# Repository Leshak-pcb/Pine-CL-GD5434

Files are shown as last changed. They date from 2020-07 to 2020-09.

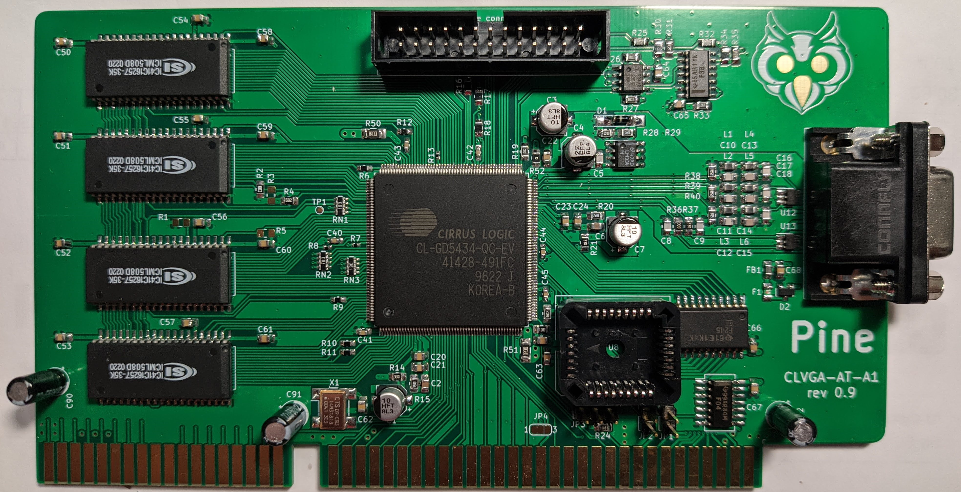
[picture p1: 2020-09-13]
Photo.jpg

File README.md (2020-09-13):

# Pine-CL-GD5434
CL-GD5434-based ISA VGA card.
Tested, works, but may still contain minor errors. Feature connector and 64k rom option are not tested yet.
Notes:
1) R1-R5 are configuration resistors, install R2 & R4 for fast DRAM, R2 & R3 for slow DRAM. Check CL-GD543x databook if you need more info.
2) U10 - optional, provides DD2B support (works with generic PCI BIOS).
3) FB1-F1-D2-C68 - DDC monitor power, remove if not using U10. D2 - BAT54 or equivalent, F1 - 200mA poly fuse.
4) U11 - optional, 93C46 used to store video modes supported by your monitor.
5) U12, U13 - optional, ESD & hot-plug protection.
6) C90-C92 - 10uF - 47uF 6.3V+
7) D1 can be replaced with 1n4148

Creative Commons Attribution-ShareAlike 4.0 International License. See https://creativecommons.org/licenses/by-sa/4.0/.

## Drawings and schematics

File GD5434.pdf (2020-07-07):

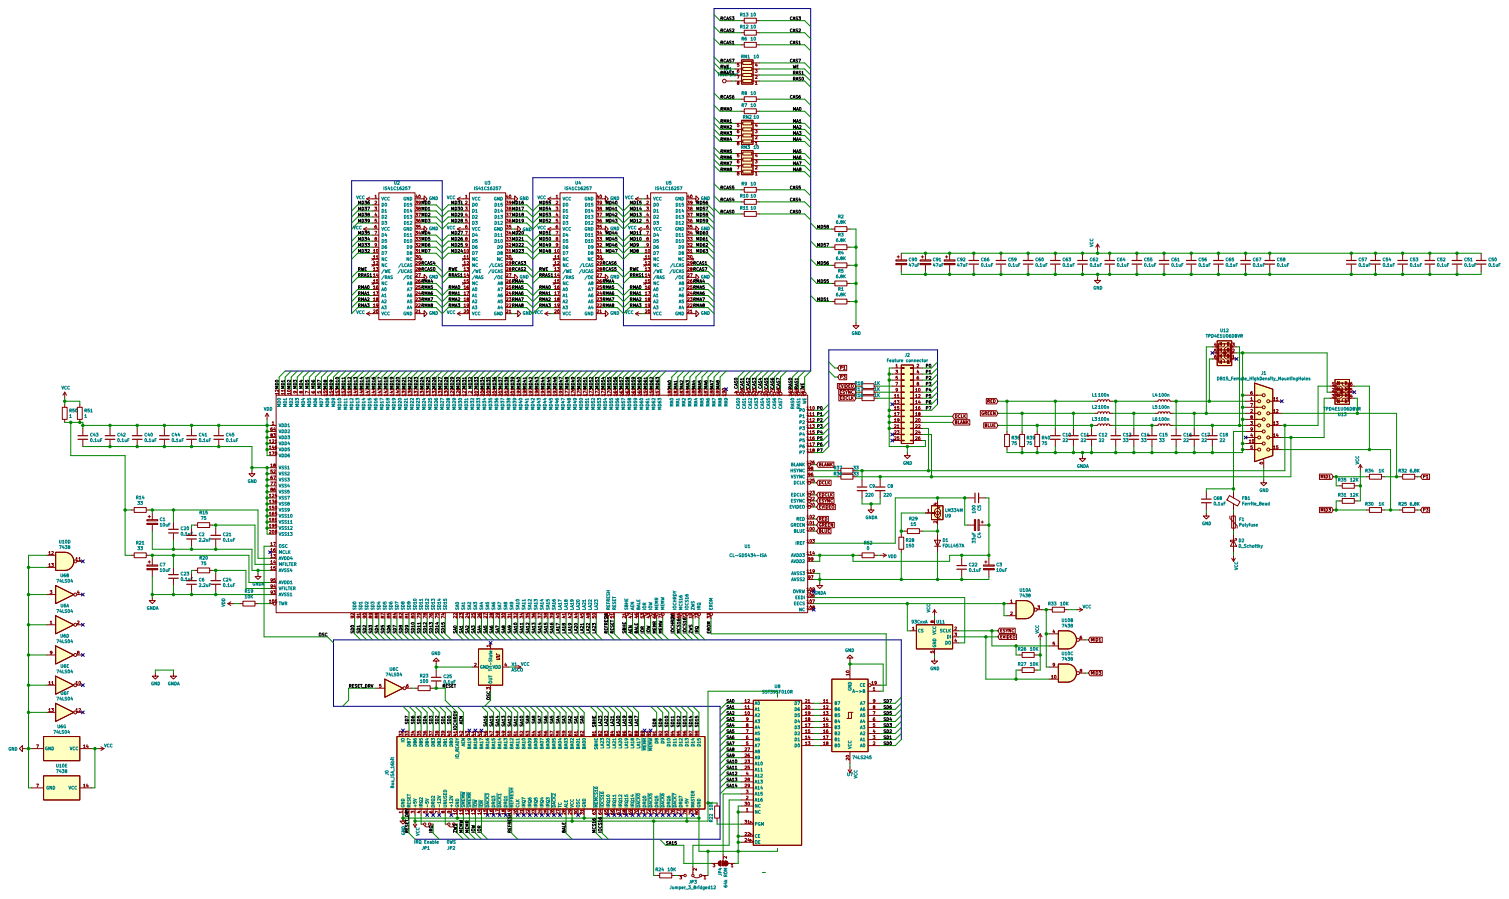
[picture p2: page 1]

4 LA17 40 LA18 41 LA19 42 IOW 43 LA20 44 LA21 45 BALE 46 AEN 47 LA22 48 IOCHRDY 49 MD7

1 GND 10 SMEMW 11 SMEMR 12 IOW 13 IOR 14 DACK3 15 DRQ3 16 DACK1 17 DRQ1 18 REFRESH 19 RESET

2 CLK 20 IRQ7 21 IRQ6 22 IRQ5 23 IRQ4 24 IRQ3 25 DACK2 26 TC 27 ALE 28 VCC 29 +5V

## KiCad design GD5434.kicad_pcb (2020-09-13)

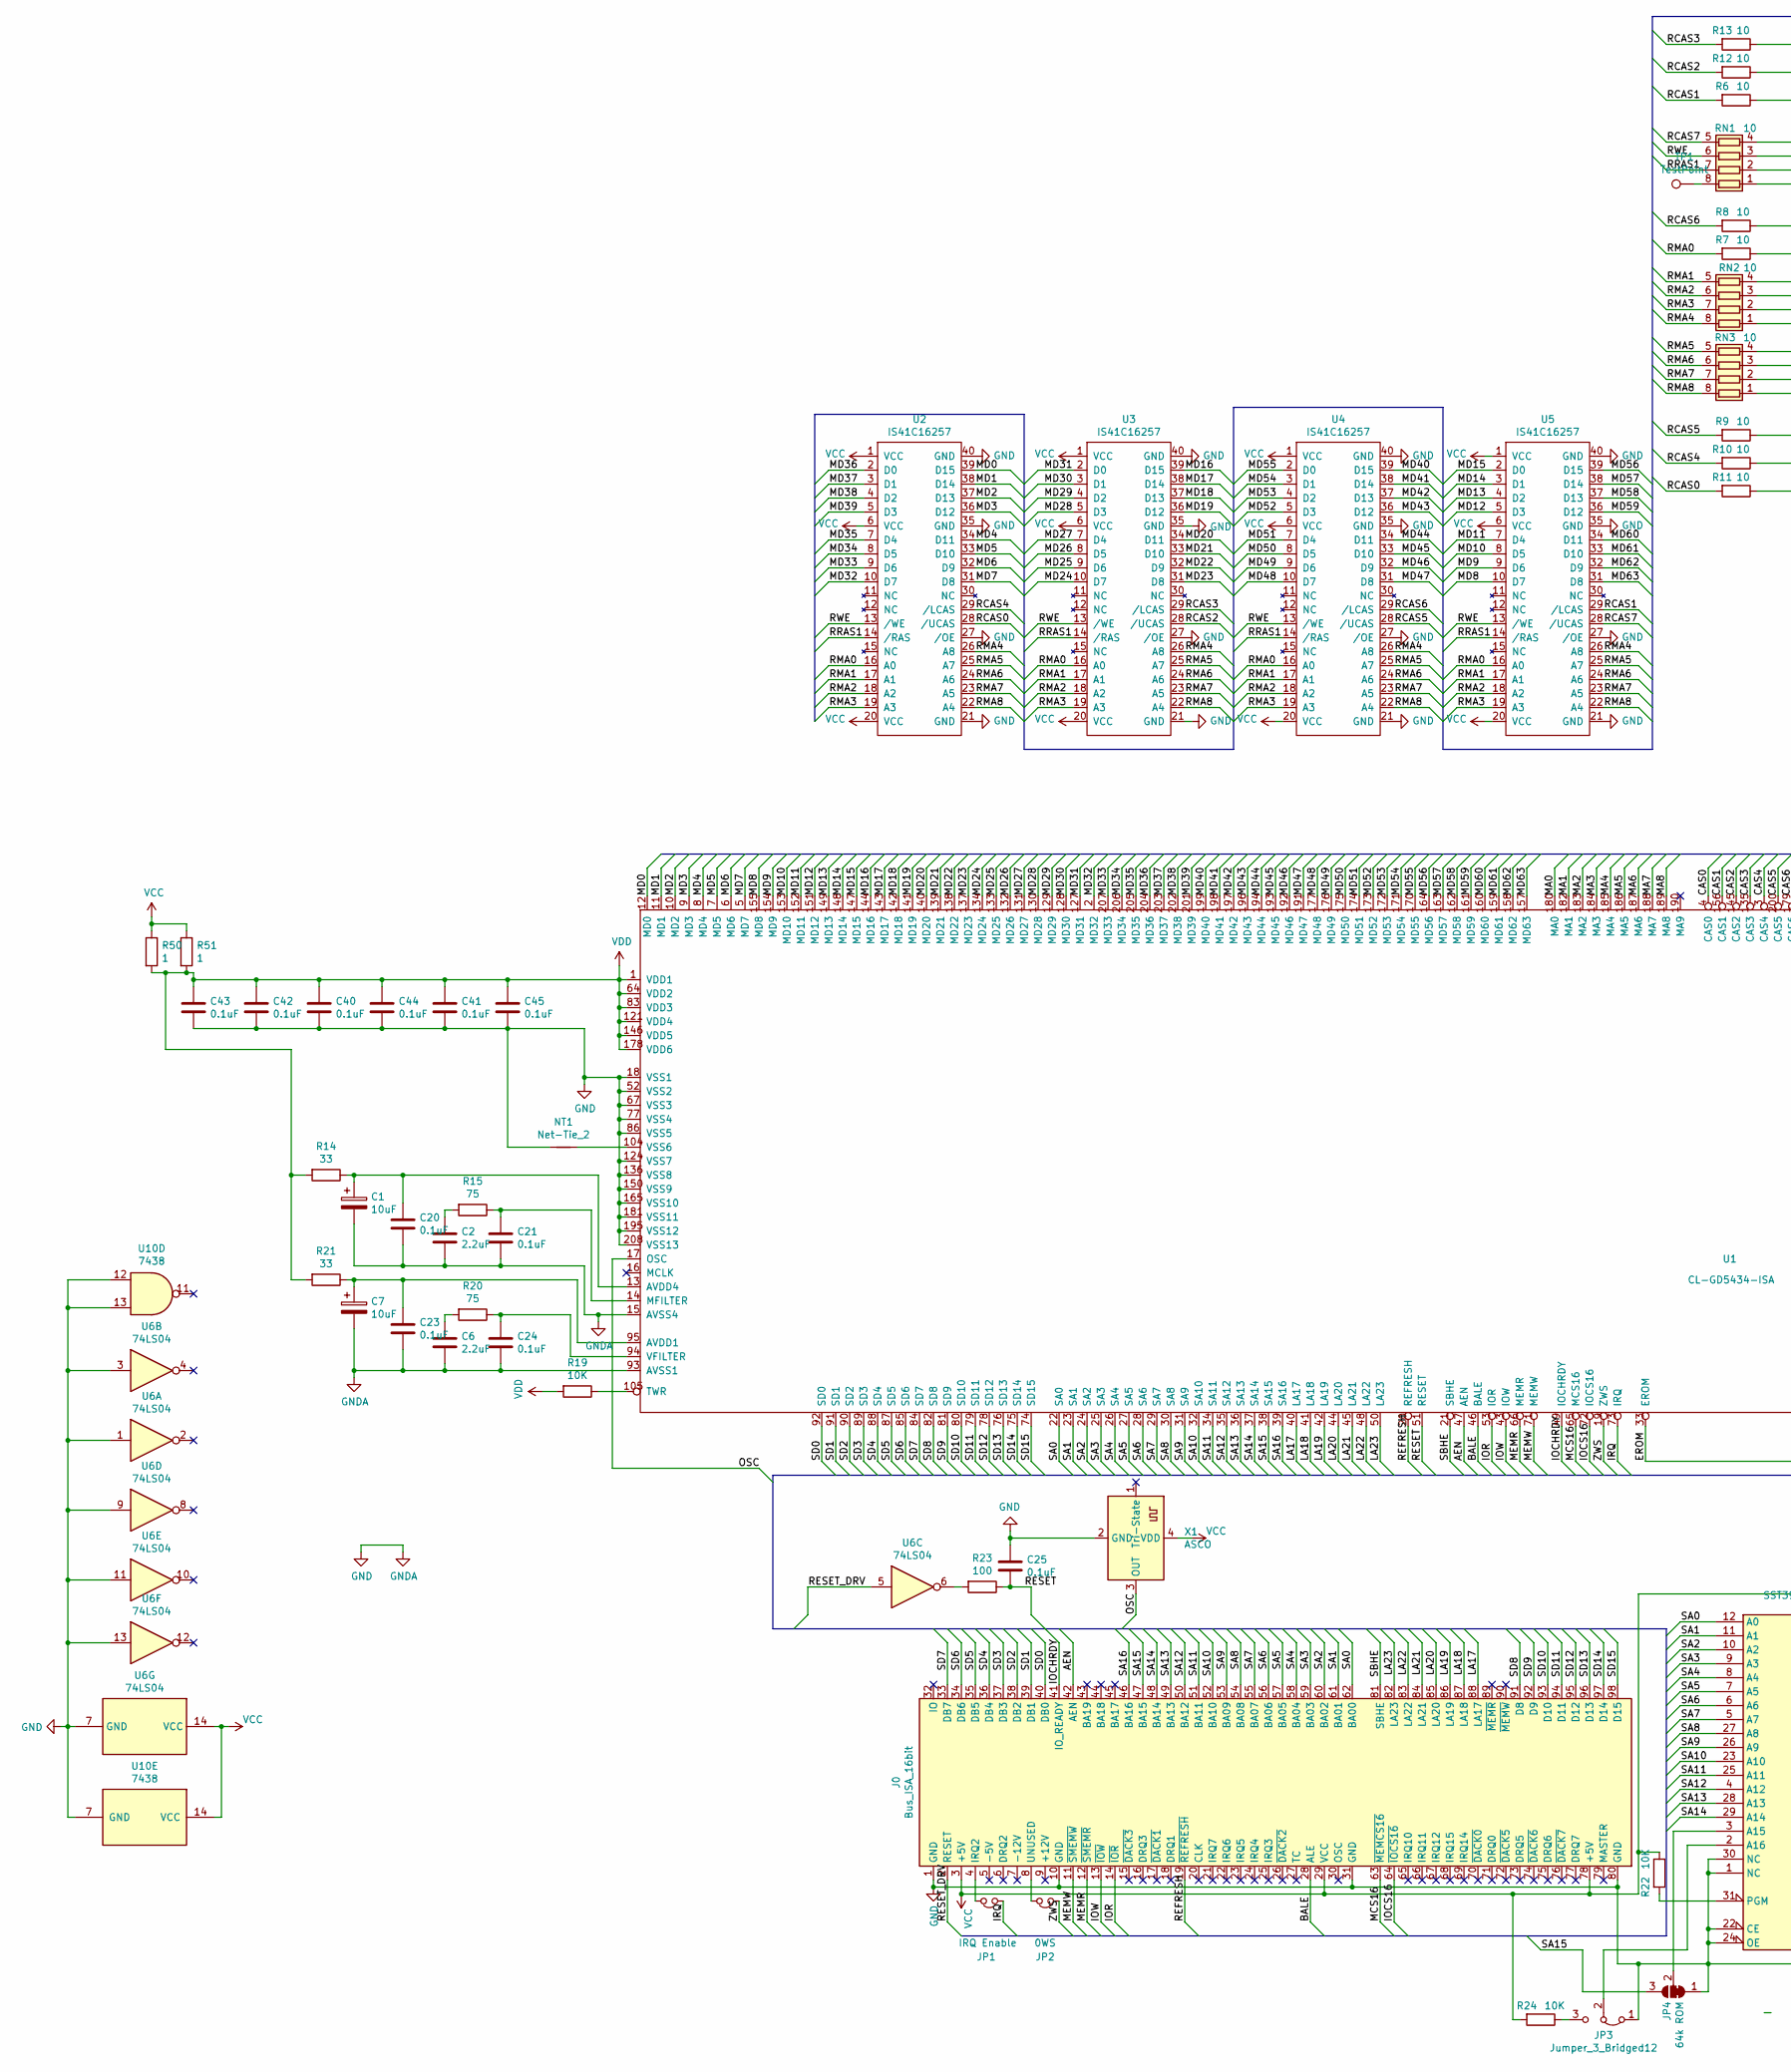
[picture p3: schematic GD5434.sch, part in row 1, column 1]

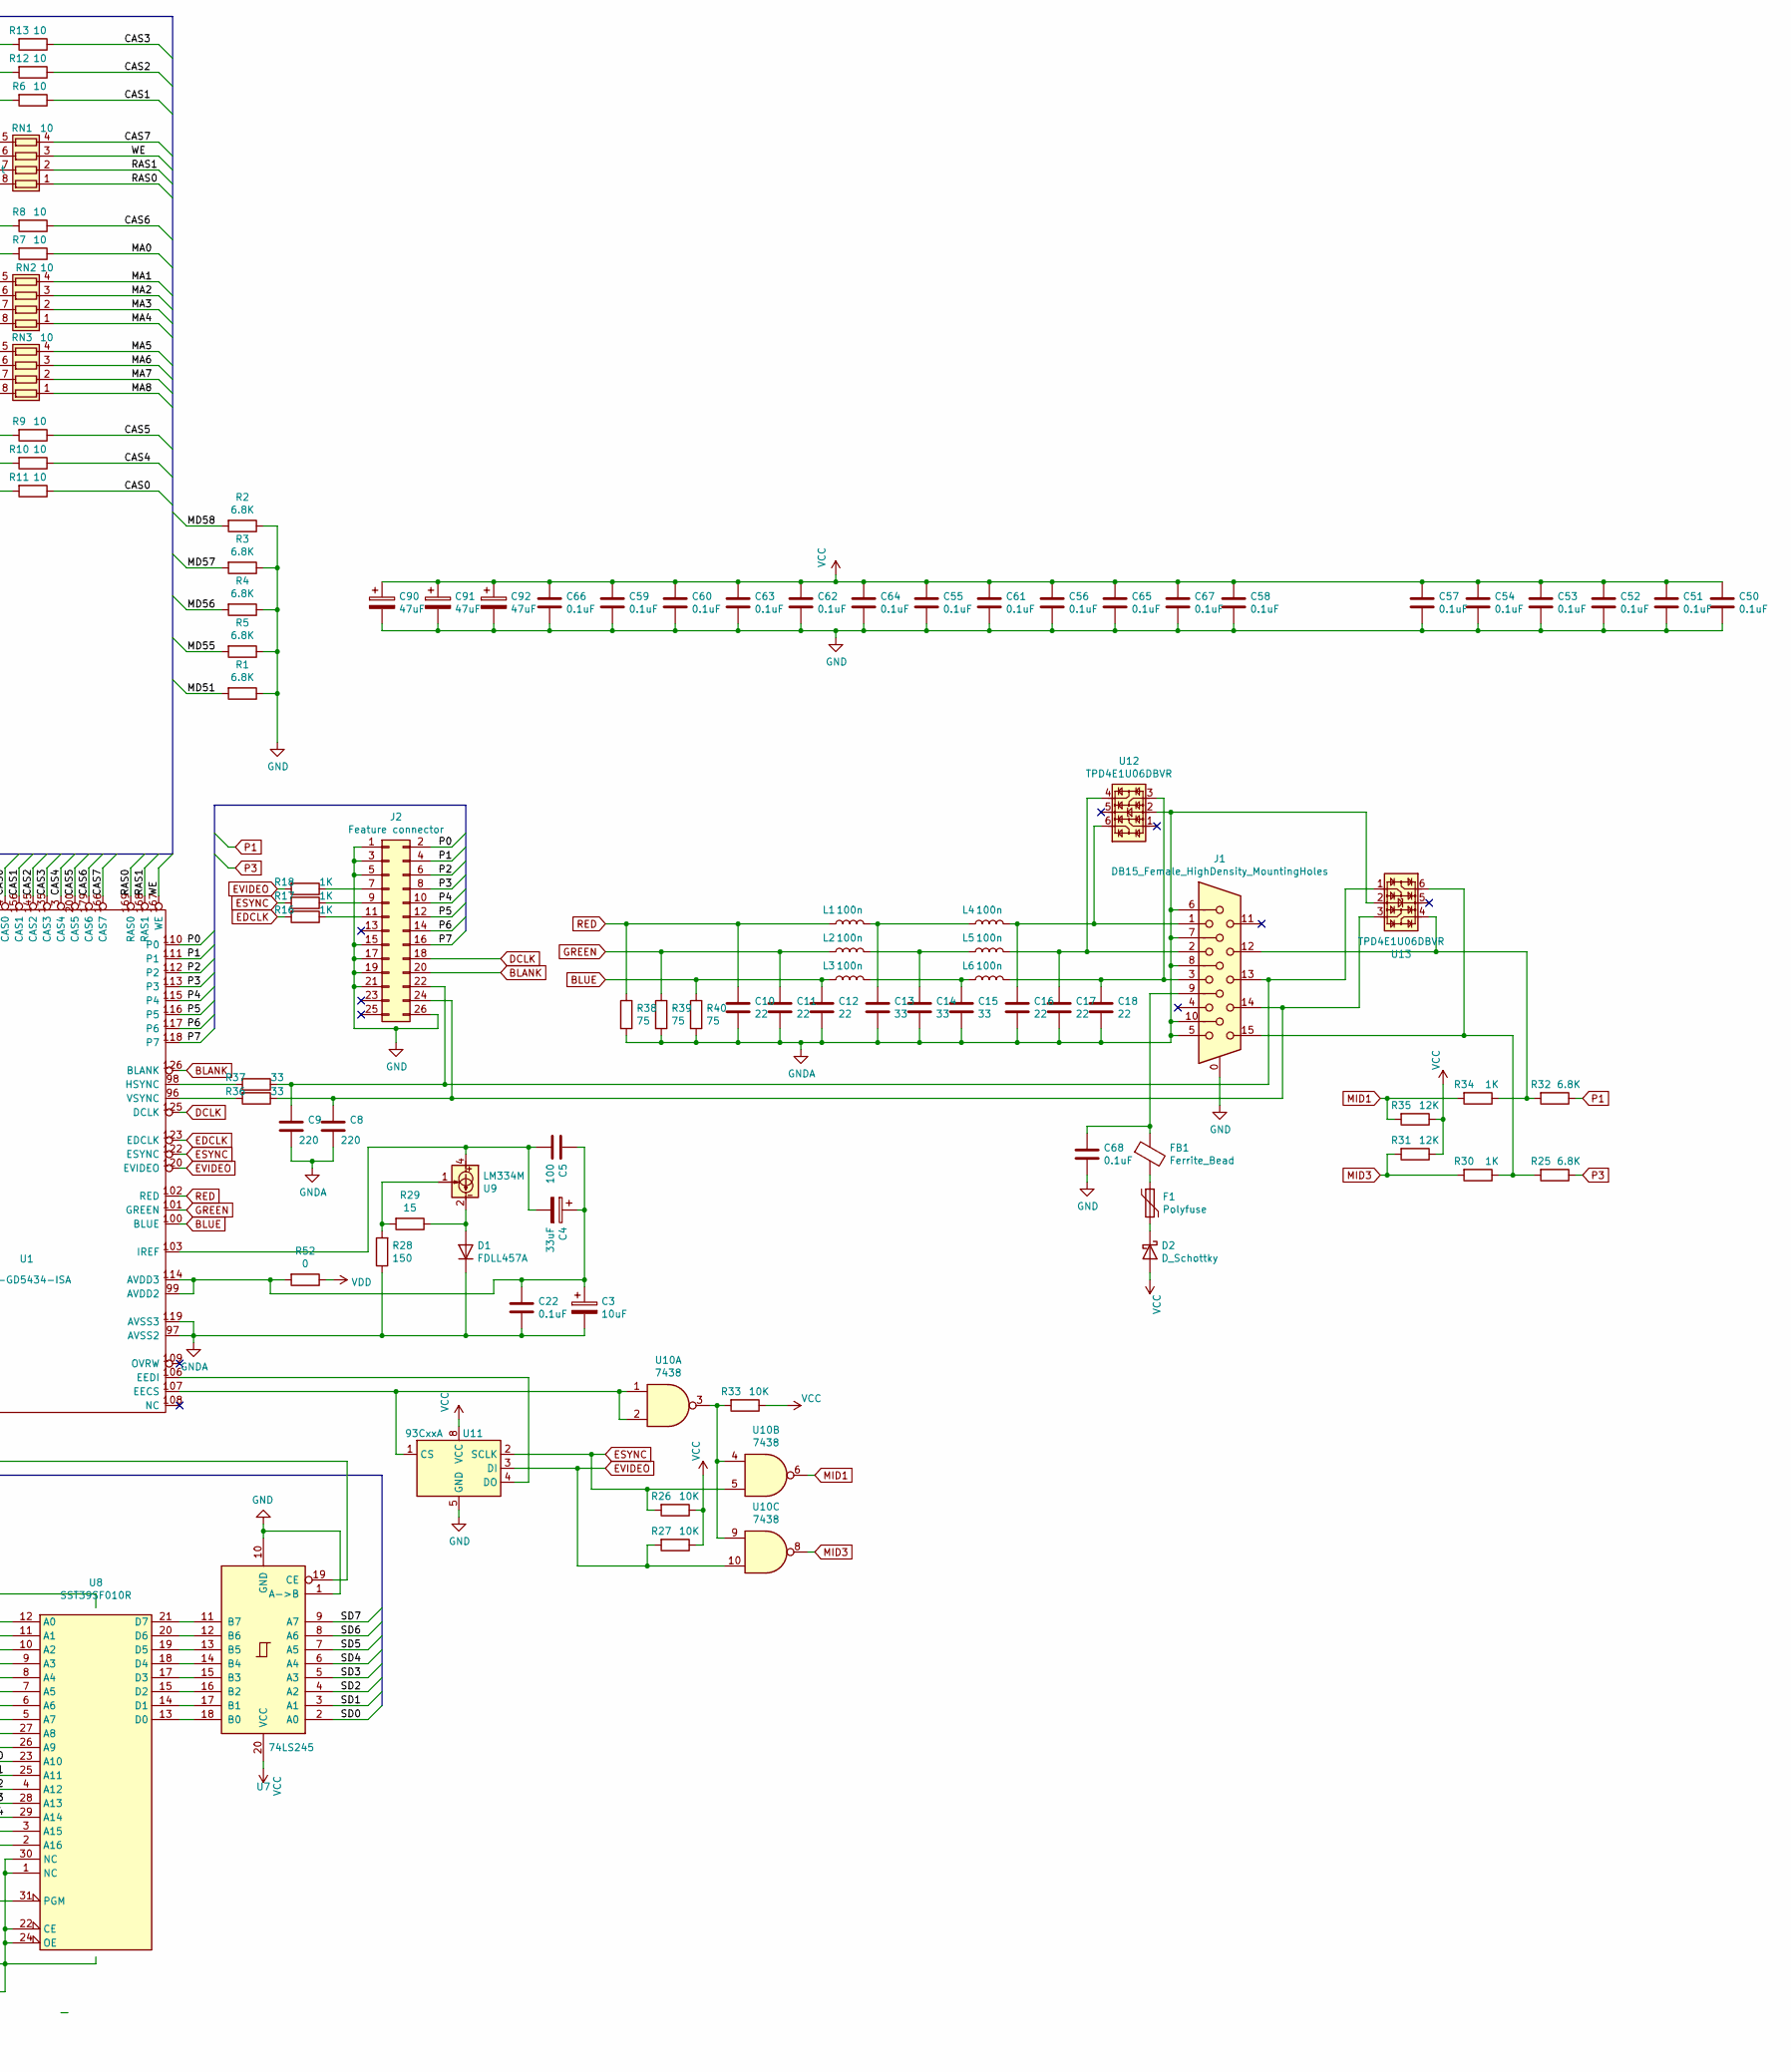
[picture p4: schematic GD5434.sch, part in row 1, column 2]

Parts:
C1, C3, C7: 10uF; CP_Elec_5x5.8
C2, C6: 2.2uF; C_0805_2012Metric_Pad1.15x1.40mm_HandSolder
C4: 33uF; C_Elec_5x5.8
C5: 100; C_0805_2012Metric_Pad1.15x1.40mm_HandSolder
C8, C9: 220; C_0805_2012Metric_Pad1.15x1.40mm_HandSolder
C10, C11, C12, C16, C17, C18: 22; C_0805_2012Metric_Pad1.15x1.40mm_HandSolder
C13, C14, C15: 33; C_0805_2012Metric_Pad1.15x1.40mm_HandSolder
C20, C21, C22, C23, C24, C25, C50, C51, C52, C53, C54, C55, C56, C57, C58, C59, C60, C61, C62, C63, C64, C65, C66, C67, C68: 0.1uF; C_0805_2012Metric_Pad1.15x1.40mm_HandSolder
C40, C41, C42, C43, C44, C45: 0.1uF; C_0603_1608Metric_Pad1.05x0.95mm_HandSolder
C90, C91, C92: 47uF; CP_Radial_D5.0mm_P2.00mm
D1: FDLL457A; D_MiniMELF_Handsoldering
D2: D_Schottky; D_SOT-23_ANK
F1: Polyfuse; Fuse_0805_2012Metric_Pad1.15x1.40mm_HandSolder
FB1: Ferrite_Bead; L_0805_2012Metric_Pad1.15x1.40mm_HandSolder
J0: Bus_ISA_16bit; BUS_AT
J1: DB15_Female_HighDensity_MountingHoles; DSUB-15-HD_Female_Horizontal_P2.29x2.54mm
J2: Feature connector; IDC-Header_2x13_P2.54mm_Vertical
JP1: IRQ Enable; PinHeader_1x02_P2.54mm_Vertical
JP2: 0WS; PinHeader_1x02_P2.54mm_Vertical
JP3: Jumper_3_Bridged12; PinHeader_1x03_P2.54mm_Vertical
JP4: 64k ROM; SolderJumper-3_P1.3mm_Bridged12_RoundedPad1.0x1.5mm_NumberL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
L1, L2, L3, L4, L5, L6: 100n; L_0805_2012Metric_Pad1.15x1.40mm_HandSolder
NT1: Net-Tie_2; NetTie-2_SMD_Pad0.5mm
R1, R2, R3, R4, R5, R25, R32: 6.8K; R_0805_2012Metric_Pad1.15x1.40mm_HandSolder
R6, R9, R10, R11, R12: 10; R_0603_1608Metric_Pad1.05x0.95mm_HandSolder
R7, R8, R13: 10; R_0402_1005Metric
R14, R21, R36, R37: 33; R_0805_2012Metric_Pad1.15x1.40mm_HandSolder
R15, R20, R38, R39, R40: 75; R_0805_2012Metric_Pad1.15x1.40mm_HandSolder
R16, R17, R18, R30, R34: 1K; R_0805_2012Metric_Pad1.15x1.40mm_HandSolder
R19, R22, R24, R26, R27, R33: 10K; R_0805_2012Metric_Pad1.15x1.40mm_HandSolder
R23: 100; R_0805_2012Metric_Pad1.15x1.40mm_HandSolder
R28: 150; R_0805_2012Metric_Pad1.15x1.40mm_HandSolder
R29: 15; R_0805_2012Metric_Pad1.15x1.40mm_HandSolder
R31, R35: 12K; R_0805_2012Metric_Pad1.15x1.40mm_HandSolder
R50, R51: 1; R_1206_3216Metric_Pad1.42x1.75mm_HandSolder
R52: 0; R_0805_2012Metric_Pad1.15x1.40mm_HandSolder
RN1, RN2, RN3: 10; R_Array_Concave_4x0603
TP1: TestPoint; TestPoint_Pad_D1.0mm
U1: CL-GD5434-ISA; PQFP-208_28x28mm_P0.5mm
U2, U3, U4, U5: IS41C16257; SOJ-40-Socket-LongPads
U6: 74LS04; SO-14_5.3x10.2mm_P1.27mm
U7: 74LS245; SOIC-20W_7.5x12.8mm_P1.27mm
U8: SST39SF010R; PLCC-32_THT-Socket
U9: LM334M; SOIC-8_3.9x4.9mm_P1.27mm
U10: 7438; SOIC-14_3.9x8.7mm_P1.27mm
U11: 93CxxA; SOIC-8_3.9x4.9mm_P1.27mm
U12, U13: TPD4E1U06DBVR; SOT-23-6_Handsoldering
X1: ASCO; Oscillator_SMD_Abracon_ASV-4Pin_7.0x5.1mm_HandSoldering

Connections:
/AEN: J0.42 (AEN), U1.47 (AEN)
/BALE: J0.28 (ALE), U1.46 (BALE)
/CAS0: R11.1, U1.4 (CAS0)
/CAS1: R6.1, U1.156 (CAS1)
/CAS2: R12.1, U1.145 (CAS2)
/CAS3: R13.1, U1.135 (CAS3)
/CAS4: R10.1, U1.3 (CAS4)
/CAS5: R9.1, U1.200 (CAS5)
/CAS6: R8.1, U1.179 (CAS6)
/CAS7: RN1.4 (R4.1), U1.166 (CAS7)
/EROM: U1.33 (EROM), U7.19 (CE)
/IOCHRDY: J0.41 (IO_READY), U1.49 (IOCHRDY)
/IOCS16: J0.64 (~IOCS16), U1.72 (IOCS16)
/IOR: J0.14 (~IOR), U1.53 (IOR)
/IOW: J0.13 (~IOW), U1.43 (IOW)
/IRQ: JP1.1, U1.73 (IRQ)
/LA17: J0.88 (LA17), U1.40 (LA17)
/LA18: J0.87 (LA18), U1.41 (LA18)
/LA19: J0.86 (LA19), U1.42 (LA19)
/LA20: J0.85 (LA20), U1.44 (LA20)
/LA21: J0.84 (LA21), U1.45 (LA21)
/LA22: J0.83 (LA22), U1.48 (LA22)
/LA23: J0.82 (LA23), U1.50 (LA23)
/MA0: R7.1, U1.180 (MA0)
/MA1: RN2.4 (R4.1), U1.182 (MA1)
/MA2: RN2.3 (R3.1), U1.183 (MA2)
/MA3: RN2.2 (R2.1), U1.184 (MA3)
/MA4: RN2.1 (R1.1), U1.185 (MA4)
/MA5: RN3.4 (R4.1), U1.186 (MA5)
/MA6: RN3.3 (R3.1), U1.187 (MA6)
/MA7: RN3.2 (R2.1), U1.188 (MA7)
/MA8: RN3.1 (R1.1), U1.189 (MA8)
/MCS16: J0.63 (~MEMCS16), U1.65 (MCS16)
/MD0: U1.12 (MD0), U2.39 (D15)
/MD1: U1.11 (MD1), U2.38 (D14)
/MD2: U1.10 (MD2), U2.37 (D13)
/MD3: U1.9 (MD3), U2.36 (D12)
/MD4: U1.8 (MD4), U2.34 (D11)
/MD5: U1.7 (MD5), U2.33 (D10)
/MD6: U1.6 (MD6), U2.32 (D9)
/MD7: U1.5 (MD7), U2.31 (D8)
/MD8: U1.155 (MD8), U5.10 (D7)
/MD9: U1.154 (MD9), U5.9 (D6)
/MD10: U1.153 (MD10), U5.8 (D5)
/MD11: U1.152 (MD11), U5.7 (D4)
/MD12: U1.151 (MD12), U5.5 (D3)
/MD13: U1.149 (MD13), U5.4 (D2)
/MD14: U1.148 (MD14), U5.3 (D1)
/MD15: U1.147 (MD15), U5.2 (D0)
/MD16: U1.144 (MD16), U3.39 (D15)
/MD17: U1.143 (MD17), U3.38 (D14)
/MD18: U1.142 (MD18), U3.37 (D13)
/MD19: U1.141 (MD19), U3.36 (D12)
/MD20: U1.140 (MD20), U3.34 (D11)
/MD21: U1.139 (MD21), U3.33 (D10)
/MD22: U1.138 (MD22), U3.32 (D9)
/MD23: U1.137 (MD23), U3.31 (D8)
/MD24: U1.134 (MD24), U3.10 (D7)
/MD25: U1.133 (MD25), U3.9 (D6)
/MD26: U1.132 (MD26), U3.8 (D5)
/MD27: U1.131 (MD27), U3.7 (D4)
/MD28: U1.130 (MD28), U3.5 (D3)
/MD29: U1.129 (MD29), U3.4 (D2)
/MD30: U1.128 (MD30), U3.3 (D1)
/MD31: U1.127 (MD31), U3.2 (D0)
/MD32: U1.2 (MD32), U2.10 (D7)
/MD33: U1.207 (MD33), U2.9 (D6)
/MD34: U1.206 (MD34), U2.8 (D5)
/MD35: U1.205 (MD35), U2.7 (D4)
/MD36: U1.204 (MD36), U2.2 (D0)
/MD37: U1.203 (MD37), U2.3 (D1)
/MD38: U1.202 (MD38), U2.4 (D2)
/MD39: U1.201 (MD39), U2.5 (D3)
/MD40: U1.199 (MD40), U4.39 (D15)
/MD41: U1.198 (MD41), U4.38 (D14)
/MD42: U1.197 (MD42), U4.37 (D13)
/MD43: U1.196 (MD43), U4.36 (D12)
/MD44: U1.194 (MD44), U4.34 (D11)
/MD45: U1.193 (MD45), U4.33 (D10)
/MD46: U1.192 (MD46), U4.32 (D9)
/MD47: U1.191 (MD47), U4.31 (D8)
/MD48: U1.177 (MD48), U4.10 (D7)
/MD49: U1.176 (MD49), U4.9 (D6)
/MD50: U1.175 (MD50), U4.8 (D5)
/MD51: R1.2, U1.174 (MD51), U4.7 (D4)
/MD52: U1.173 (MD52), U4.5 (D3)
/MD53: U1.172 (MD53), U4.4 (D2)
/MD54: U1.171 (MD54), U4.3 (D1)
/MD55: R5.2, U1.170 (MD55), U4.2 (D0)
/MD56: R4.2, U1.164 (MD56), U5.39 (D15)
/MD57: R3.2, U1.163 (MD57), U5.38 (D14)
/MD58: R2.2, U1.162 (MD58), U5.37 (D13)
/MD59: U1.161 (MD59), U5.36 (D12)
/MD60: U1.160 (MD60), U5.34 (D11)
/MD61: U1.159 (MD61), U5.33 (D10)
/MD62: U1.158 (MD62), U5.32 (D9)
/MD63: U1.157 (MD63), U5.31 (D8)
/MEMR: J0.12 (~SMEMR), U1.66 (MEMR)
/MEMW: J0.11 (~SMEMW), U1.71 (MEMW)
/OSC: U1.17 (OSC), X1.3 (OUT)
/P0: J2.2, U1.110 (P0)
/P2: J2.6, U1.112 (P2)
/P4: J2.10, U1.115 (P4)
/P5: J2.12, U1.116 (P5)
/P6: J2.14, U1.117 (P6)
/P7: J2.16, U1.118 (P7)
/RAS0: RN1.1 (R1.1), U1.169 (RAS0)
/RAS1: RN1.2 (R2.1), U1.168 (RAS1)
/RCAS0: R11.2, U2.28 (/UCAS)
/RCAS1: R6.2, U5.29 (/LCAS)
/RCAS2: R12.2, U3.28 (/UCAS)
/RCAS3: R13.2, U3.29 (/LCAS)
/RCAS4: R10.2, U2.29 (/LCAS)
/RCAS5: R9.2, U4.28 (/UCAS)
/RCAS6: R8.2, U4.29 (/LCAS)
/RCAS7: RN1.5 (R4.2), U5.28 (/UCAS)
/REFRESH: J0.19 (~REFRESH), U1.20 (REFRESH)
/RESET: C25.2, R23.1, U1.51 (RESET)
/RESET_DRV: J0.2 (RESET), U6.5
/RMA0: R7.2, U2.16 (A0), U3.16 (A0), U4.16 (A0), U5.16 (A0)
/RMA1: RN2.5 (R4.2), U2.17 (A1), U3.17 (A1), U4.17 (A1), U5.17 (A1)
/RMA2: RN2.6 (R3.2), U2.18 (A2), U3.18 (A2), U4.18 (A2), U5.18 (A2)
/RMA3: RN2.7 (R2.2), U2.19 (A3), U3.19 (A3), U4.19 (A3), U5.19 (A3)
/RMA4: RN2.8 (R1.2), U2.26 (A8), U3.26 (A8), U4.26 (A8), U5.26 (A8)
/RMA5: RN3.5 (R4.2), U2.25 (A7), U3.25 (A7), U4.25 (A7), U5.25 (A7)
/RMA6: RN3.6 (R3.2), U2.24 (A6), U3.24 (A6), U4.24 (A6), U5.24 (A6)
/RMA7: RN3.7 (R2.2), U2.23 (A5), U3.23 (A5), U4.23 (A5), U5.23 (A5)
/RMA8: RN3.8 (R1.2), U2.22 (A4), U3.22 (A4), U4.22 (A4), U5.22 (A4)
/RRAS1: RN1.7 (R2.2), U2.14 (/RAS), U3.14 (/RAS), U4.14 (/RAS), U5.14 (/RAS)
/RWE: RN1.6 (R3.2), U2.13 (/WE), U3.13 (/WE), U4.13 (/WE), U5.13 (/WE)
/SA0: J0.62 (BA00), U1.22 (SA0), U8.12 (A0)
/SA1: J0.61 (BA01), U1.23 (SA1), U8.11 (A1)
/SA2: J0.60 (BA02), U1.24 (SA2), U8.10 (A2)
/SA3: J0.59 (BA03), U1.25 (SA3), U8.9 (A3)
/SA4: J0.58 (BA04), U1.26 (SA4), U8.8 (A4)
/SA5: J0.57 (BA05), U1.27 (SA5), U8.7 (A5)
/SA6: J0.56 (BA06), U1.28 (SA6), U8.6 (A6)
/SA7: J0.55 (BA07), U1.29 (SA7), U8.5 (A7)
/SA8: J0.54 (BA08), U1.30 (SA8), U8.27 (A8)
/SA9: J0.53 (BA09), U1.31 (SA9), U8.26 (A9)
/SA10: J0.52 (BA10), U1.32 (SA10), U8.23 (A10)
/SA11: J0.51 (BA11), U1.34 (SA11), U8.25 (A11)
/SA12: J0.50 (BA12), U1.35 (SA12), U8.4 (A12)
/SA13: J0.49 (BA13), U1.36 (SA13), U8.28 (A13)
/SA14: J0.48 (BA14), U1.37 (SA14), U8.29 (A14)
/SA15: J0.47 (BA15), JP4.3 (B), U1.38 (SA15)
/SA16: J0.46 (BA16), U1.39 (SA16)
/SBHE: J0.81 (SBHE), U1.21 (SBHE)
/SD0: J0.40 (DB0), U1.92 (SD0), U7.2 (A0)
/SD1: J0.39 (DB1), U1.91 (SD1), U7.3 (A1)
/SD2: J0.38 (DB2), U1.90 (SD2), U7.4 (A2)
/SD3: J0.37 (DB3), U1.89 (SD3), U7.5 (A3)
/SD4: J0.36 (DB4), U1.88 (SD4), U7.6 (A4)
/SD5: J0.35 (DB5), U1.87 (SD5), U7.7 (A5)
/SD6: J0.34 (DB6), U1.85 (SD6), U7.8 (A6)
/SD7: J0.33 (DB7), U1.84 (SD7), U7.9 (A7)
/SD8: J0.91 (D8), U1.82 (SD8)
/SD9: J0.92 (D9), U1.81 (SD9)
/SD10: J0.93 (D10), U1.80 (SD10)
/SD11: J0.94 (D11), U1.79 (SD11)
/SD12: J0.95 (D12), U1.78 (SD12)
/SD13: J0.96 (D13), U1.76 (SD13)
/SD14: J0.97 (D14), U1.75 (SD14)
/SD15: J0.98 (D15), U1.74 (SD15)
/WE: RN1.3 (R3.1), U1.167 (WE)
/ZWS: JP2.1, U1.19 (ZWS)
BLANK: J2.20, U1.126 (BLANK)
BLUE: C12.1, L3.1, R40.1, U1.100 (BLUE)
DCLK: J2.18, U1.125 (DCLK)
EDCLK: R16.2, U1.123 (EDCLK)
ESYNC: R17.2, R26.2, U1.122 (ESYNC), U10.5, U11.2 (SCLK)
EVIDEO: R18.2, R27.2, U1.120 (EVIDEO), U10.10, U11.3 (DI)
GND: C1.2, C2.2, C3.2, C6.2, C7.2, C8.2, C9.2, C10.2, C11.2, C12.2, C13.2, C14.2, C15.2, C16.2, C17.2, C18.2, C20.2, C21.2, C22.2, C23.2, C24.2, C25.1, C40.2, C41.2, C42.2, C43.2, C44.2, C45.2, C50.2, C51.2, C52.2, C53.2, C54.2, C55.2, C56.2, C57.2, C58.2, C59.2, C60.2, C61.2, C62.2, C63.2, C64.2, C65.2, C66.2, C67.2, C68.2, C90.2, C91.2, C92.2, D1.1 (K), J0.1 (GND), J0.10 (GND), J0.31 (GND), J0.80 (GND), J1.0, J1.5, J1.6, J1.7, J1.8, J1.10, J2.1, J2.3, J2.5, J2.15, J2.17, J2.19, J2.21, J2.26, JP3.1 (A), JP4.1 (A), NT1.1, R1.1, R2.1, R3.1, R4.1, R5.1, R28.1, R38.2, R39.2, R40.2, U1.15 (AVSS4), U1.18 (VSS1), U1.52 (VSS2), U1.67 (VSS3), U1.77 (VSS4), U1.86 (VSS5), U1.93 (AVSS1), U1.97 (AVSS2), U1.119 (AVSS3), U1.124 (VSS7), U1.136 (VSS8), U1.150 (VSS9), U1.165 (VSS10), U1.181 (VSS11), U1.195 (VSS12), U1.208 (VSS13), U2.21 (GND), U2.27 (/OE), U2.35 (GND), U2.40 (GND), U3.21 (GND), U3.27 (/OE), U3.35 (GND), U3.40 (GND), U4.21 (GND), U4.27 (/OE), U4.35 (GND), U4.40 (GND), U5.21 (GND), U5.27 (/OE), U5.35 (GND), U5.40 (GND), U6.1, U6.3, U6.7 (GND), U6.9, U6.11, U6.13, U7.1 (A->B), U7.10 (GND), U8.1 (NC), U8.16 (GND), U8.22 (CE), U8.24 (OE), U8.30 (NC), U10.7 (GND), U10.12, U10.13, U11.5 (GND), U12.2, U13.2, X1.2 (GND)
GREEN: C11.1, L2.1, R39.1, U1.101 (GREEN)
MID1: R34.2, R35.2, U10.6
MID3: R30.2, R31.2, U10.8
unnamed: C1.1, C20.1, R14.1, U1.13 (AVDD4)
unnamed: C2.1, R15.2
unnamed: C4.2, C5.2, U1.103 (IREF), U9.4
unnamed: C6.1, R20.2
unnamed: C8.1, J1.14, J2.24, R36.1, U13.3
unnamed: C9.1, J1.13, J2.22, R37.1, U13.1
unnamed: C13.1, L1.2, L4.1
unnamed: C14.1, L2.2, L5.1
unnamed: C15.1, L3.2, L6.1
unnamed: C16.1, J1.1, L4.2, U12.6
unnamed: C17.1, J1.2, L5.2, U12.4
unnamed: C18.1, J1.3, L6.2, U12.3
unnamed: C21.1, R15.1, U1.14 (MFILTER)
unnamed: C3.1, C4.1, C5.1, C22.1, R52.2, U1.99 (AVDD2), U1.114 (AVDD3)
unnamed: C7.1, C23.1, R21.1, U1.95 (AVDD1)
unnamed: C24.1, R20.1, U1.94 (VFILTER)
unnamed: C68.1, FB1.1, J1.9
unnamed: D1.2 (A), R29.1, U9.2, U9.3, U9.6, U9.7
unnamed: D2.1 (K), F1.2
unnamed: F1.1, FB1.2
unnamed: J0.4 (IRQ2), JP1.2
unnamed: J0.8 (UNUSED), JP2.2
unnamed: J1.12, R32.2, R34.1, U13.4
unnamed: J1.15, R25.2, R30.1, U13.6
unnamed: J2.7, R18.1
unnamed: J2.9, R17.1
unnamed: J2.11, R16.1
unnamed: JP3.2 (C), U8.2 (A16)
unnamed: JP3.3 (B), R24.1
unnamed: JP4.2 (C), U8.3 (A15)
unnamed: NT1.2, U1.104 (VSS6)
unnamed: R19.1, U1.105 (TWR)
unnamed: R22.2, U8.31 (PGM)
unnamed: R23.2, U6.6
unnamed: R28.2, R29.2, U9.1
unnamed: R33.2, U10.3, U10.4, U10.9
unnamed: R36.2, U1.96 (VSYNC)
unnamed: R37.2, U1.98 (HSYNC)
unnamed: RN1.8 (R1.2), TP1.1
unnamed: U1.106 (EEDI), U11.4 (DO)
unnamed: U1.107 (EECS), U10.1, U10.2, U11.1 (CS)
unnamed: U7.11 (B7), U8.21 (D7)
unnamed: U7.12 (B6), U8.20 (D6)
unnamed: U7.13 (B5), U8.19 (D5)
unnamed: U7.14 (B4), U8.18 (D4)
unnamed: U7.15 (B3), U8.17 (D3)
unnamed: U7.16 (B2), U8.15 (D2)
unnamed: U7.17 (B1), U8.14 (D1)
unnamed: U7.18 (B0), U8.13 (D0)
P1: J2.4, R32.1, U1.111 (P1)
P3: J2.8, R25.1, U1.113 (P3)
RED: C10.1, L1.1, R38.1, U1.102 (RED)
VCC: C50.1, C51.1, C52.1, C53.1, C54.1, C55.1, C56.1, C57.1, C58.1, C59.1, C60.1, C61.1, C62.1, C63.1, C64.1, C65.1, C66.1, C67.1, C90.1, C91.1, C92.1, D2.2 (A), J0.3 (+5V), J0.29 (VCC), J0.78 (+5V), R22.1, R24.2, R26.1, R27.1, R31.1, R33.1, R35.1, R50.1, R51.1, U2.1 (VCC), U2.6 (VCC), U2.20 (VCC), U3.1 (VCC), U3.6 (VCC), U3.20 (VCC), U4.1 (VCC), U4.6 (VCC), U4.20 (VCC), U5.1 (VCC), U5.6 (VCC), U5.20 (VCC), U6.14 (VCC), U7.20 (VCC), U8.32 (VCC), U10.14 (VCC), U11.8 (VCC), X1.4 (VDD)
VDD: C40.1, C41.1, C42.1, C43.1, C44.1, C45.1, R14.2, R19.2, R21.2, R50.2, R51.2, R52.1, U1.1 (VDD1), U1.64 (VDD2), U1.83 (VDD3), U1.121 (VDD4), U1.146 (VDD5), U1.178 (VDD6)

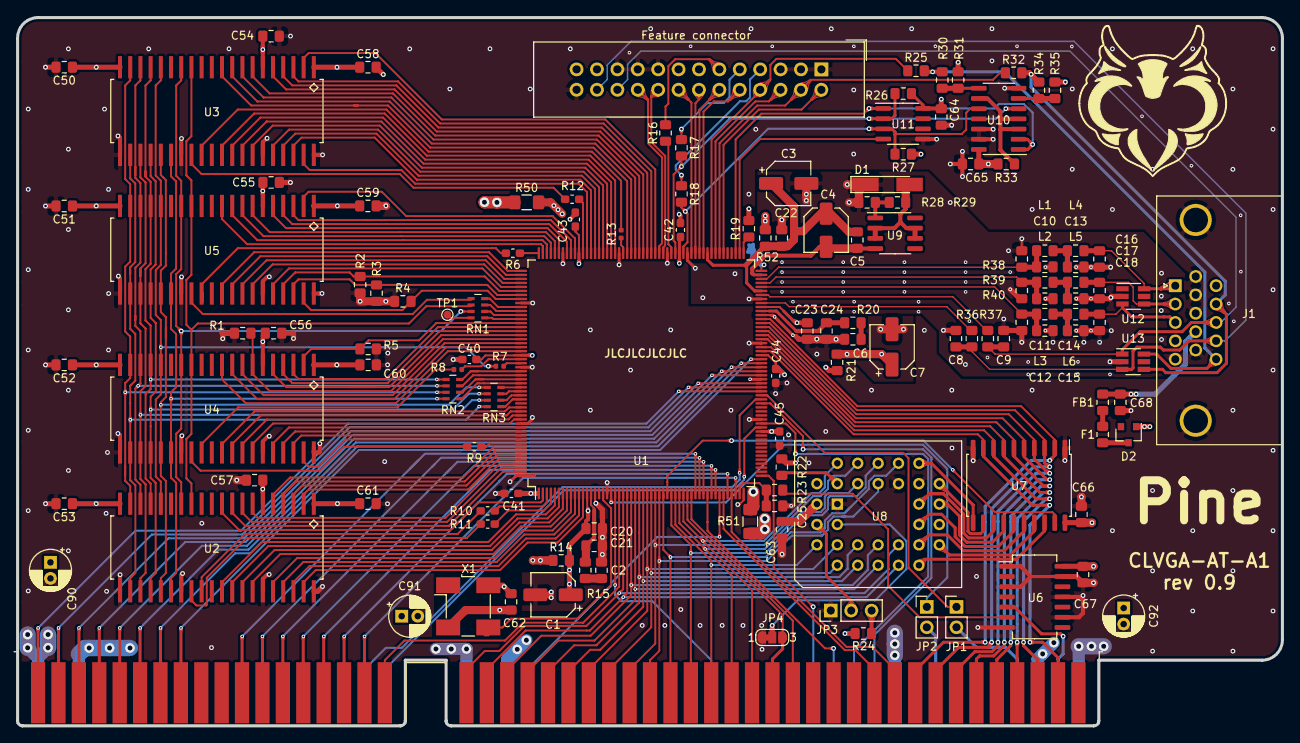
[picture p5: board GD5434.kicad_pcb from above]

Board: 4 copper layers, 157.5 x 88.2 mm, 131 parts (1 on the bottom side), 230 nets.

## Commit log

2020-07-05 Add files via upload
    V0.9 PCB & schematics
    [GD5434.kicad_pcb, GD5434.sch]
2020-07-07 Add files via upload
    fixed 74LS245 connections
    [GD5434-B_Cu.gbr, GD5434-B_Mask.gbr, GD5434-B_SilkS.gbr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]
2020-09-13 Add files via upload
    Few updates + BOM
    [GD5434-B_Cu.gbr, GD5434-B_Mask.gbr, GD5434-B_SilkS.gbr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]
